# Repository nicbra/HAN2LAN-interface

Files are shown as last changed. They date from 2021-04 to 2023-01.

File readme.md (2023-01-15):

# HAN-to-WLAN interface module
This is a hardware project where the readings of electrical power-meters will be interfaced for logging and display without further interaction with external servers and third-party vendors.

## Hardware
The hardware-module are developed with the Aidon-meters in mind, which is the most used power-meter in eastern Norway.
The hardware-module is a standalone module powered by the HAN-port of the AMS-meter without the neccesity of external power supply. For Aidon, there is a maximum current delivery of 30 mA, which is the highest ammount among the AMS-vendors used in Norway.

## Data parsing
This repository contains only the hardware. You can either write your own firmware for the ESP8266, but I recommend using [AmsToMqttBridge](https://github.com/gskjold/AmsToMqttBridge) from GSkjold.

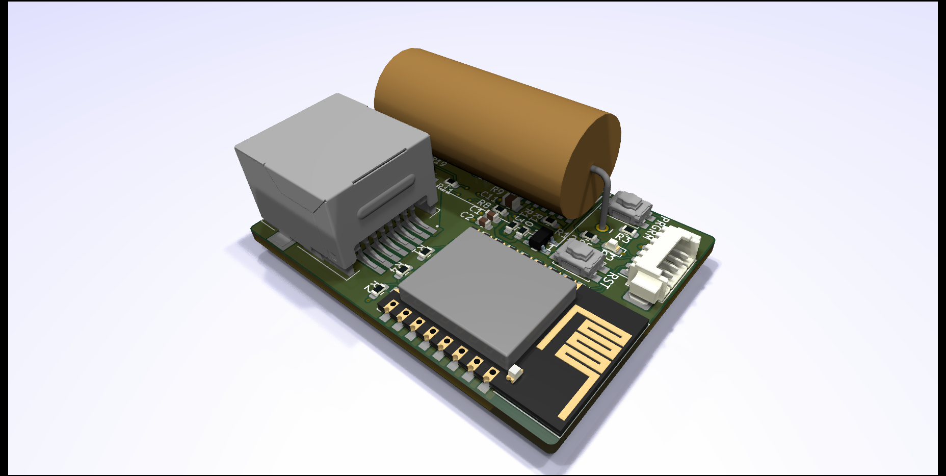
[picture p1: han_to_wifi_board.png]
PCB render


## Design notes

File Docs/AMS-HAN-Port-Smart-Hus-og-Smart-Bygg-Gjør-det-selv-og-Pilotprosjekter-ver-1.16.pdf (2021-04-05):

## Bruk av HAN-port - Gjør-det-selv Smart Hus/Bygg Løsning testet for NURI AMS Måler Bortfall av S0 og bruk av HAN port, versjon 1.15, 2018.06.26

## Bakgrunn

Hele e-verksbransjen og nettselskaper tilknyttet SORIA-alliansen starter nå utskifting av alle våre elektrisitets energimålere til nye AMS målere. Dette gjennomføres i løpet av 2 år framover. Teknologien vi benytter for dagens kWh-måling/fjernavlesning som leverer energipulser (S0) fases ut ved bytte til ny AMS måler.
NEK (https//www.nek.no) har vært sentral mht. standardisering av HAN-porten. Her er det lagt ut informasjon til:
- Utviklere (https://www.nek.no/info-ams-han-utviklere/)
- Brukere (https://www.nek.no/info-ams-han-brukere/)

AMS-måleren som SORIA-alliansen ruller ut vil medføre tilpasning fra nettkunder/leverandører som tidligere har benyttet energipulser (S0) fra dagens målere. Noen av disse kundene bruker denne porten til bl.a. å styre SD anlegg.
De nye AMS målerne for Norge kommer med HAN (Home Area Network) port der måleren kan, om kunden ønsker sende ut data om nåverdier for effektuttaket (kW), energiforbruket (kWh) og strøm- (A) og spenningsforhold (V). Den fysiske pluggen er en RJ45. Det elektriske grensesnittet er basert på MBUS standarden, som leverer nok strøm til at et HAN-adapter kan tilknyttes porten som oversetter meldingene til trådløst format ikke trenger ekstra strømforsyning. Applikasjonsprotokollen er basert på DLMS. Sistnevnte protokoll sender ut meldinger om nevnte strømstørrelser i form av OBIS koder. AMS måler har også en optisk port (IEC 62056-21), men denne er av sikkerhetsmessige grunner stengt fra fabrikken og kan ikke benyttes av kunden.
Flere kraftleverandører har fått Enova-midler til å utvikle en adapter til HAN-porten.
Nettselskapet sin rolle er kun som tilrettelegger for smart hus/smartbygg via den nye standarden for datatilgangen fra den nye AMS måleren.
Oppstilt i OSI-modellen gir dette følgende kommunikasjonsstack:

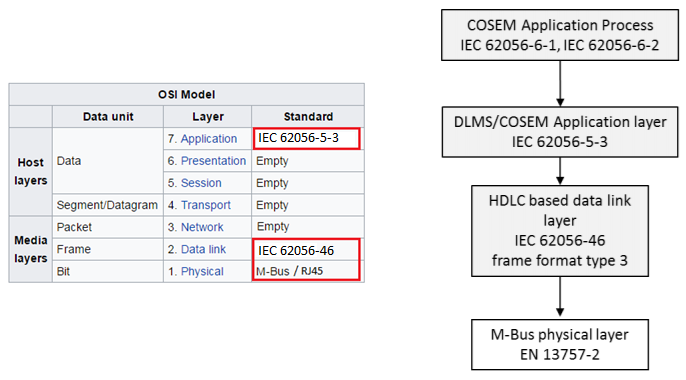
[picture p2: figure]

Fig 1. Protokoller og OSI-modell Fysisk Interface / M-BUS:
- HAN-porten (AMS-måler) er M-Bus Master og kommuniserer BARE med M-Bus SLAVER
- Leverer spenning som er nok til å drive M-Bus SLAVE i andre enden med moderat strømforbruk
- Fysisk Plugg: RJ45
- Baud settings: Hastighet=2400 bit/s, Byte = 8 bit, Parity = Even, Stop bits=1
- Pinner som benyttes: Pin1 og Pin2

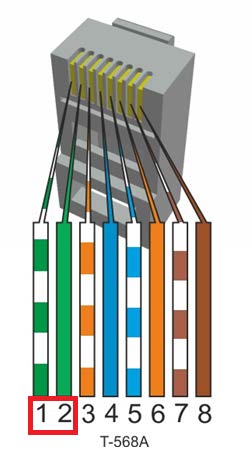
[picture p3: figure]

Fig. RJ45 – Pin1 og Pin2 for MBUS

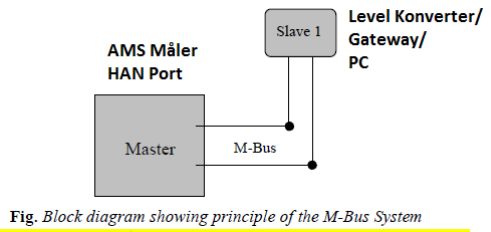
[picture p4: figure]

For HAN-porten er det viktig å merke seg at det BARE skal monteres EN MBUS Slave!
Slaven på HAN-porten skal aldri sende tilbake data til Master (AMS Måler). Om en Slave skulle finne på å sende data til Master vil disse data vil uansett bli ignorert/forkastet av Master.
Overføring av 0/1 bits fra master til slave utføres ved å regulere spenningsnivået. Når det skal sendes ut en logisk
- "1"-er bit benyttes en spenning på +36 V.
- "0"-er bit benyttes en spenning på +24V
Overføring av data fra slave til master skjer ved å endre strømforbruket i slaven:
- En "1"-er bit sendes ved å forbruke opp til 1.5 mA
- En logisk "0"-er bit sendes ved å øke strømforbruket til 11-20 mA

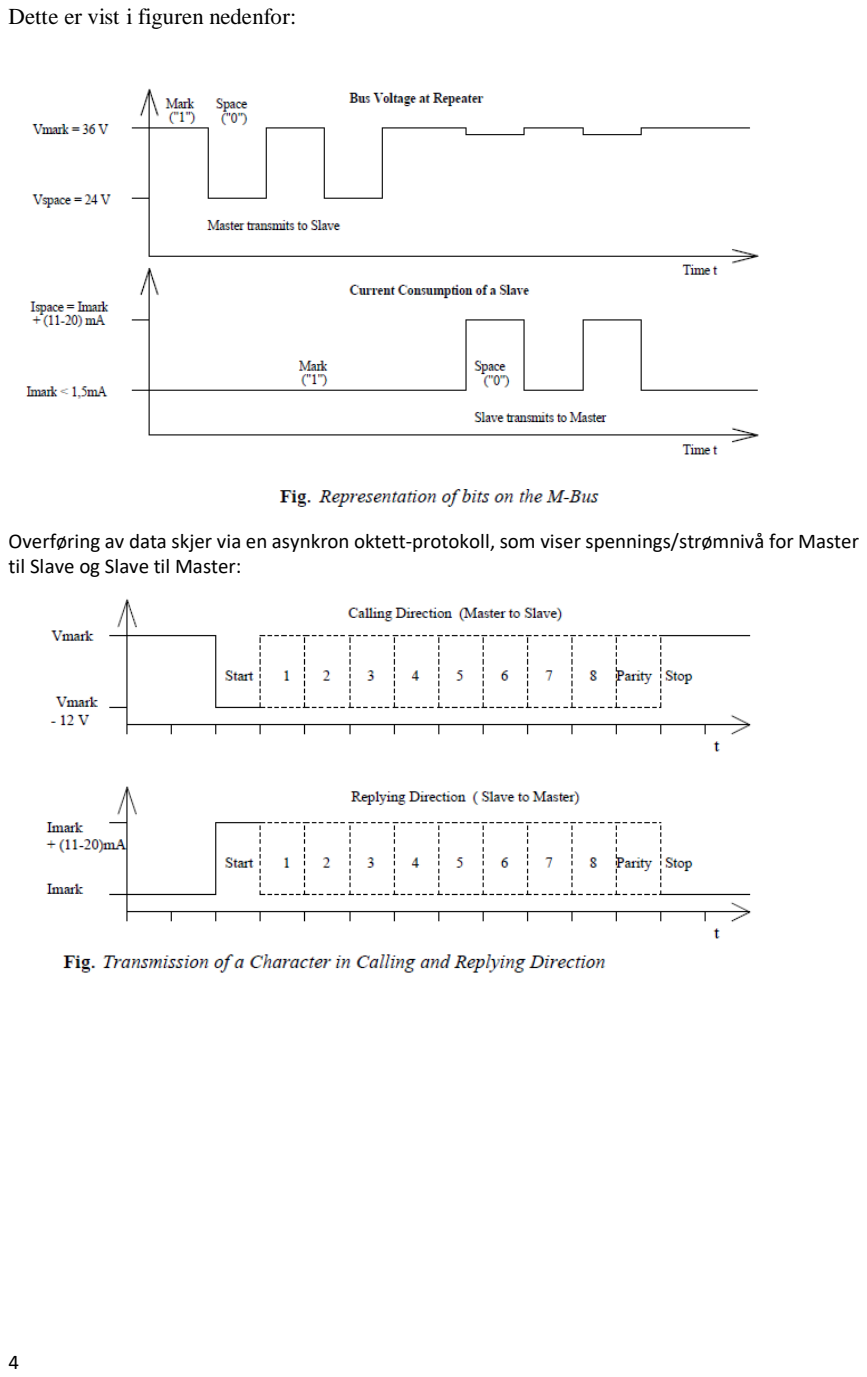
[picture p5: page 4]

Dette er vist i figuren nedenfor:

Overføring av data skjer via en asynkron oktett-protokoll, som viser spennings/strømnivå for Master til Slave og Slave til Master:

Meldingsformatet som kommer ut gir tilgang på følgende verdier:
- Effekt ++ hver 2. sekund
- Effekt ++ og Leveringskvalitet hvert 10. sekund
- Effekt ++, Leveringskvalitet og Energiforbuk (målerstand) hver time

Målerstand i forhold til forrige målerstand vil for en direktekoblet måler tilsvarer det energivolumet som blir oversendt Elhub hver 60 (15) minutt.

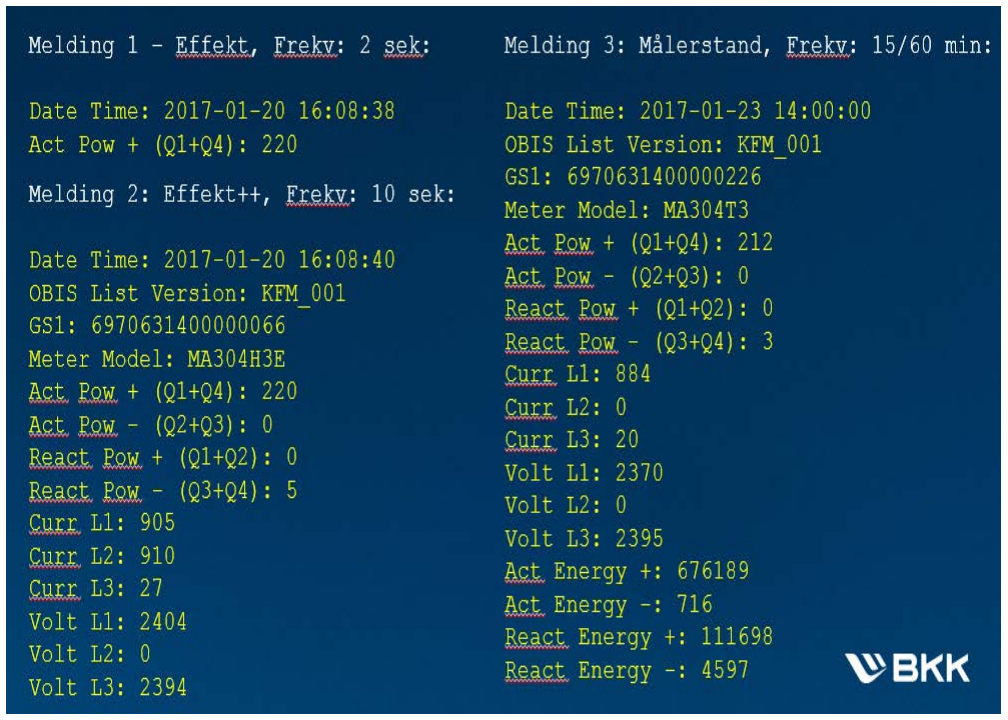
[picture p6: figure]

Fig 2. Eksempel på utskrift av telegrammene

Hvordan bygge en generell Gateway til andre systemer som Z-Wave, KNX etc:

En mulighet er å bruke følgende løsning for en embedded gateway:
- Adapterløsning 1: MBUS til USB med 2 stk. adaptere
- MBUS SLAVE til RS232 (drives av strøm fra HAN-porten)

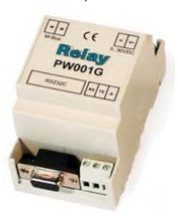
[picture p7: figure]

- USB-til-RS232 kabel (og får strøm fra USB-port) mellom RPi og Relay PW001G
- Søk med «rs232 to usb»

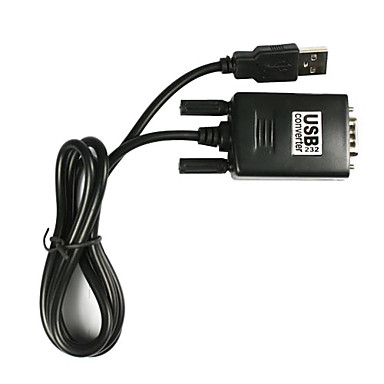
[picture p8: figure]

- Adapterløsning 2 (AliExpress m.fl.): MBUS SLAVE til USB med 1 stk. adapter
- Søk med: «site:aliexpress.com usb to mbus slave»

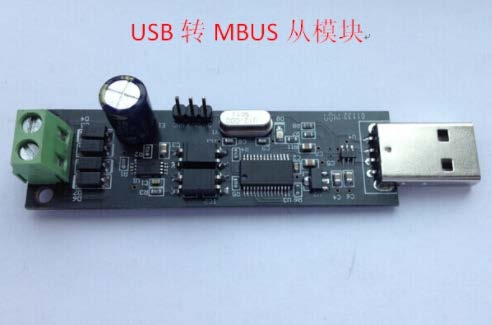
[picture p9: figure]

- Adapterløsning 3: USB-til-M-BUS adapter/kabel (denne har vi bare fått til å virke med Parity = Even som skulle vært None)
- Søk med: «site:aliexpress.com usb to mbus slave»

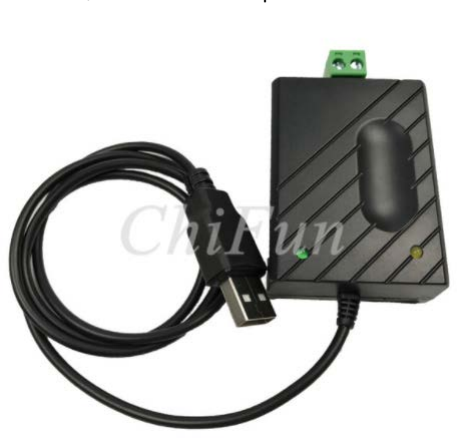
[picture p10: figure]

HAN-Port GW-programvaren kan kjøres på Raspberry Pi (RPi) og derfra interface smartbygg gatewayer fra KNX etc.
Dersom en kjører Raspian (Debian) på RPi dukker serieporten opp som /dev/ttyUSB0 Komponentvalget er her bare en illustrasjon over noe som er å få tak i og som vil virke. MBUS kabel består av et enkelt trådpar.

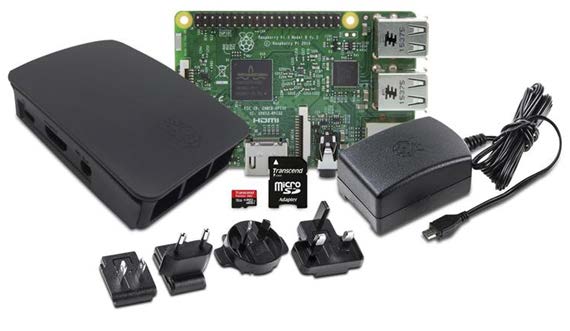
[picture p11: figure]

Fig. Eksempel på RPi kit for å bygge HAN-Gateway
- Søk med «raspberry pi pris»

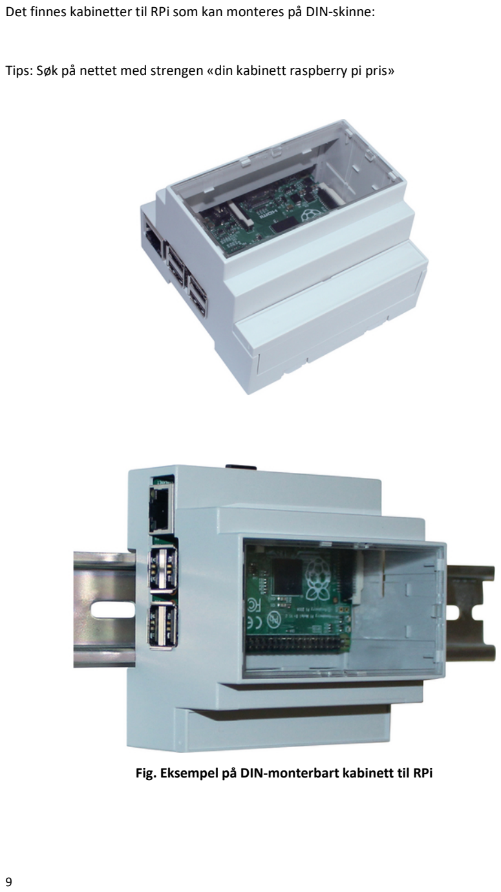
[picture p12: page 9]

Det finnes kabinetter til RPi som kan monteres på DIN-skinne:

Tips: Søk på nettet med strengen «din kabinett raspberry pi pris»

Fig. Eksempel på DIN-monterbart kabinett til RPi

# Figurer - Sammenkobling

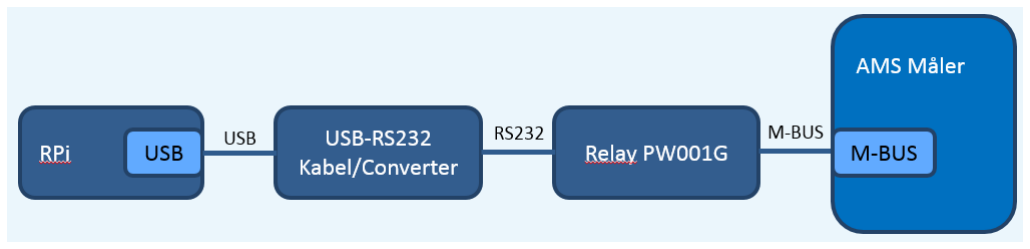
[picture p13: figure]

Fig. Adapterløsning 1 – RS232 til MBUS i egen adapter (Relay PW001G)

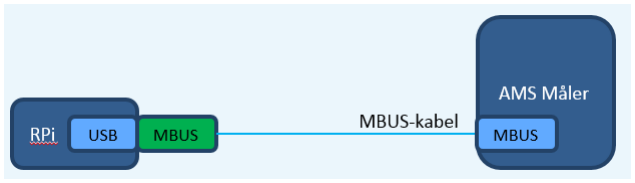
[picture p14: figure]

Fig. Adapterløsning 2 - USB innstikkskort m/ integrert RS232/MBUS konverter

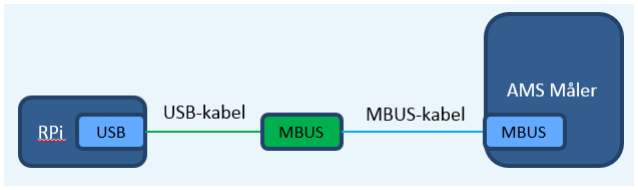
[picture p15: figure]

Fig. Adapterløsning 3 – USB-kabel-til-MBUS-adapter

## Testprogramvare av HAN-port

Programvare for å teste ut eller bruke HAN-porten kan lastes ned fra denne linken: https://drive.google.com/drive/folders/0B3ZvFI0Dg1TDbDBzMU02cnU0Y28?usp=sharing

Programvaren er «as is» og gir ingen rett til reklamasjon eller support fra nettselskapet. Programvaren er bare testet mot Kaifa målere.

## Vedlegg: Kaifa sin implementasjon av NVE / NEK OBIS Spesifikasjon

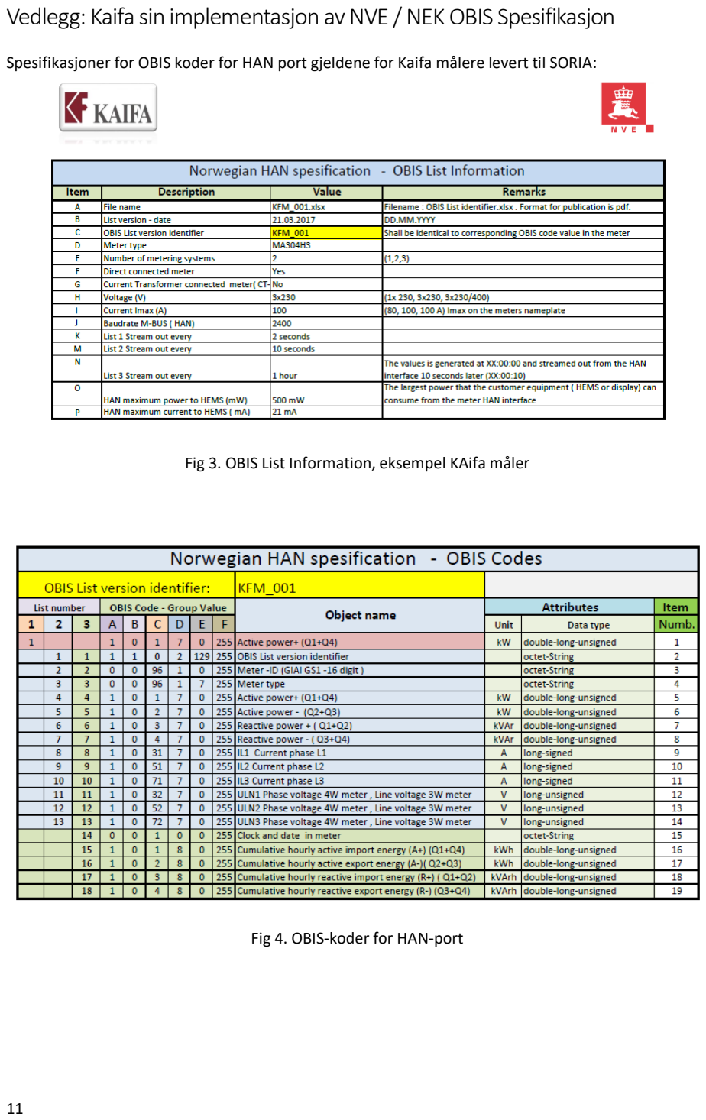
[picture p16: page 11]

Spesifikasjoner for OBIS koder for HAN port gjeldene for Kaifa målere levert til SORIA:

Fig 3. OBIS List Information, eksempel KAifa måler

Fig 4. OBIS-koder for HAN-port

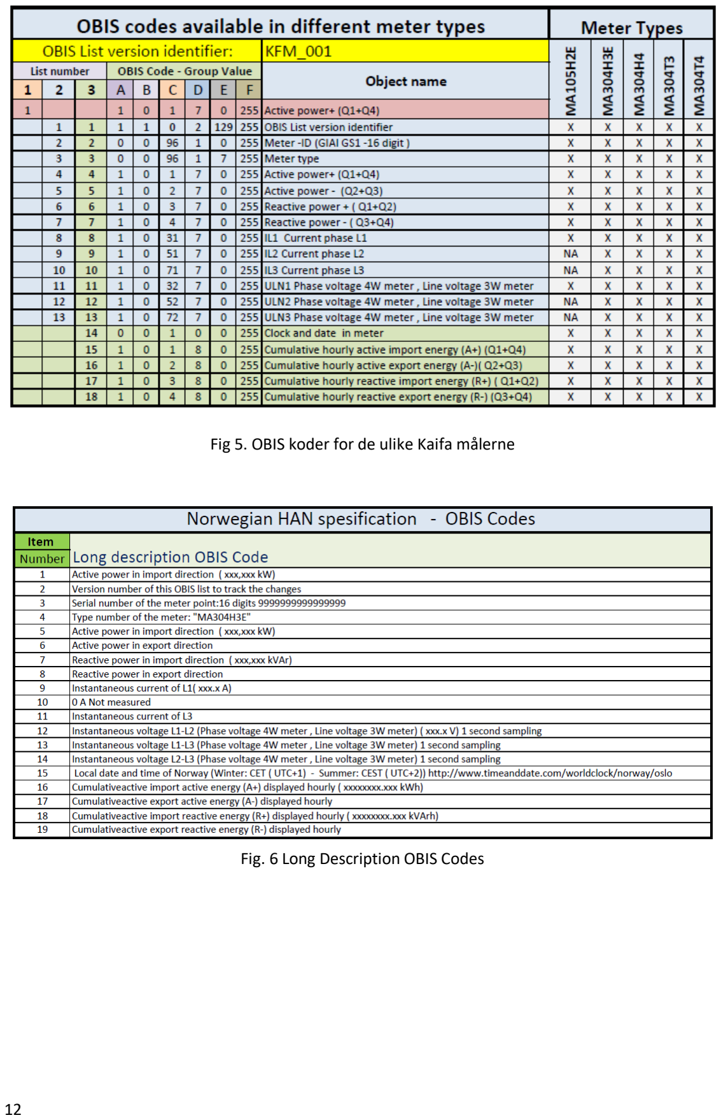
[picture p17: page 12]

Fig 5. OBIS koder for de ulike Kaifa målerne

Fig. 6 Long Description OBIS Codes

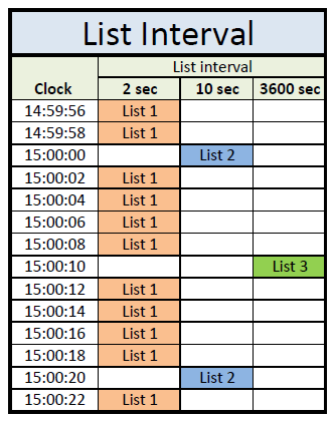
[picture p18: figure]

Fig. 7 Frekvens av telegrammer

# Bruk av HAN-PORT programvare - noen eksempler

## 1. Kildekoden som er på brikken:

### cd ~/src/han-port Oppdaterte tar-filer har katalognavn på formen han-port-<release> Utrulling: cd ~/src <lagre .tar filen her> tar xvf han-port-<release>.tar cd ~/src/han-port-<release>

1.1 Kompiler:

### make clean make

## 2. Hjelp / Hvordan bruke 'test_rx':

### Etter at du har koblet til USB-kabel kommer det dynamisk en ny USB device som typisk heter /dev/ttyUSB0 (hvis dette er den første tty-

USB enheten).

### 2.1 Utfør kommandoen:

### «ls -l /dev/tty* | grep -i usb»

før og etter at du har installert USB donglelen.

### 2.2 Gjør enheten tilgjengelig for vanlige brukere (som root/superbruker):

### sudo su chmod 666 /dev/ttyUSB0 Dette må (pga sikkerheten i Raspbian) gjøres hver gang USB dongelen plugges i! En "quick & dirty" løsning kan være å legge inn 'chmod 666

/dev/ttyUSB0' i en cron jobb som kjøres hvert 5 sekund.

### 2.2 Bruk av test_rx programmet:

### ./test_rx -h

### 2.3 Replay fra fil:

### ./test_rc -f han-data-MA105H2E-2017-01-26_08:00-11:00.dat

### 2.4 Replay fra fil logget fra kryptert HAN-port fil:

### ./test_rx -f han-data-MA105H2E-C00112233445566778899AABBCCDDEEFF-2017-01-25_08:00-12:00.dat -k 00112233445566778899AABBCCDDEEFF

### 2.5 Logging til fil USB/RS232 adapteret mitt som dukker opp som /dev/ttyUSB0 (se hva

som er lagt inn default MACRO i Makefile):

### ./test_rx -d /dev/ttyUSB0

### 2.6 Bare logging til skjerm:

### ./test_rx -n -d /dev/ttyUSB0

### 2.7 Multicast meldingene videre på LAN-et:

### ./test_rx -m -n -d /dev/ttyUSB0

### 2.8 Multicast meldingene som leses fra fil, lager 1s pause etter hver multicast sending

### ./test_rx -M -f han-data-MA304T3-2017-01-23_13:03-15:57.dat

### 2.9 Mottak av multicast fra en annen pi/pc/whatever

### ./test_rx -l

### 2.10 Setting av paritet

Vi har testet en MBUS «dongle» som har tolker paritet feil. Paritet skal være N(one), men den må i visse tilfeller settes til E(ven) eller O(dd). Hvis det ikke virker, prøv alternativ paritet med:

### ./test_rx -n -P E eller ./test_rc -n P O

# Markedsaktører

## Smart Hus / Smart Bygg

Utviklere av HAN-adapter og SW løsninger:

- EM Systemer (Smart Bygg?)
- http://www.emsystemer.no/
- Hark Technology (Smart Hus?)
- http://www.harktech.no/
- Red Bridge (Smart Hus?)
- http://redbridge.no
- Sikom Living (Smart Hus?)
- http://www.sikom.no/nb
- Vord (Smart Hus?)
- https://vord.no/

## Do-It-Yourself (DIY) prosjekter

Det finnes også entusiaster som har laget HW/SW-løsninger til HAN-porten. På Github ligger det beskrivelse av hvordan kyndige kan bygge sin egen adapter for WiFi og som får energiforsyning fra HAN-porten. Her ligger det også programvare for bruk av adapteren.

https://github.com/roarfred

Det er uklart om noen vil overta vedlikeholdet eller videreutvikling av denne programvaren.

## Enova støttede AMS-prosjekter

Enova sin link til prosjekjene:

- https://www.enova.no/privat/smarte-strommalere-ams/enova-og-ams/
Formål:

Prosjektet skal avdekke hvilke typer løsninger som er best egnet til å motivere til å spare
strøm. Dette blir et nyttig prosjekt for bransjen som helhet. Nå vil man ikke lenger trenge å spekulere på hva som vil fungere, nå finner vi det ut. 25 000 strømabonnenter er et stort utvalg som vil gi pålitelige svar om hva slags type løsninger som virker og ikke virker.

Her vil det komme tekniske løsninger for sanntidskommunikasjon fra HAN-porten, de første vil forventes å komme mot slutten av Q4 2017.
Eksempel på løsning fra Fjordkraft:

Pilotkunden får to «dongler» som er fabrikkparet slik at det bare skal monteres, ingen konfigurasjon er aktivering er nødvendig. Data sendes kryptert hvert 2. sekund til en tjeneste i «skyen».

Dongle 1:

Kobles til HAN-port på måler og trekker strøm fra HAN-porten. Den sender data kryptert på radio i 868 MHz fribruksområdet til Dongle 2 som vist i bildet under:

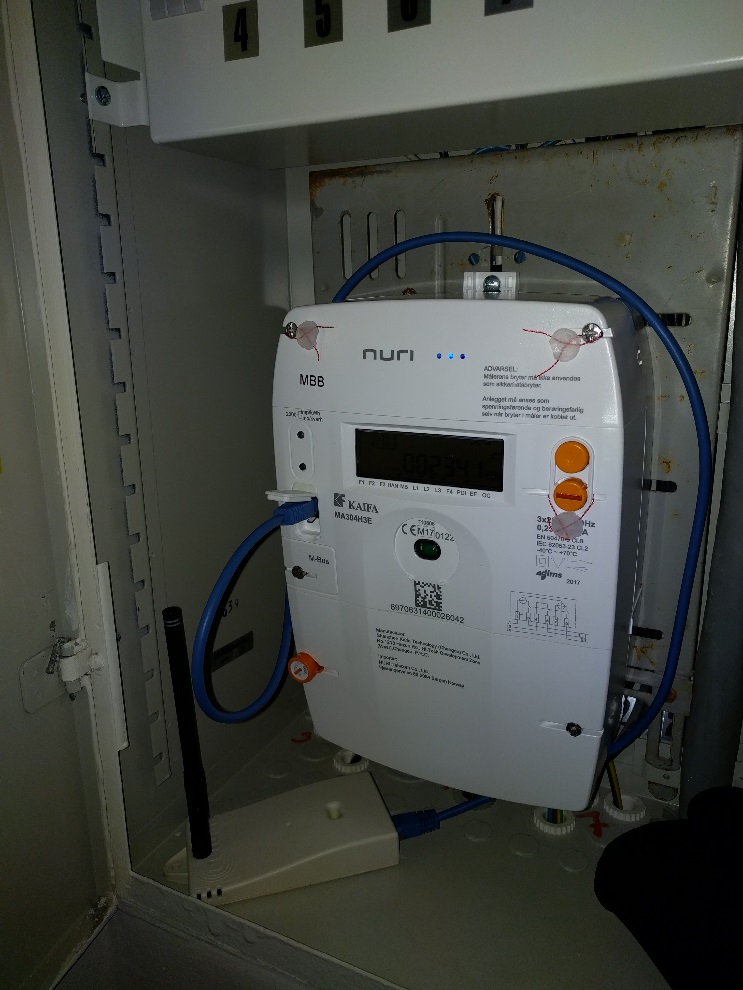
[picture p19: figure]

Fig. HAN dongle koblet til HAN-port

Dongle 2:

Denne kobles til en ethernett port på en hjemmeruter (typisk en WiFi ruter) og mottar data fra Dongle 1. Dongle 2 sender data videre kryptert via Internettlinjen til en skytjeneste.

Dongle 2 må forsynes med strøm via en Mikro-USB kabel som vist i bildet under:

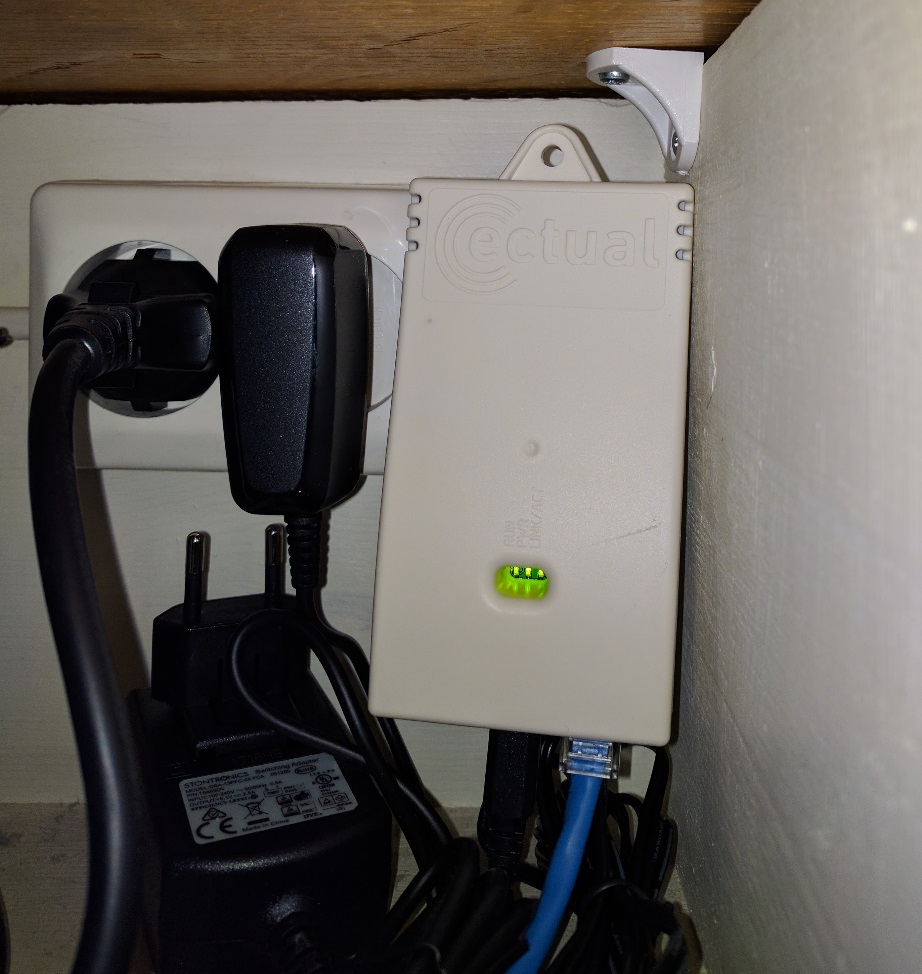
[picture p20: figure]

Fig. Tilknytning av Hjemmeruter-dongle

Skytjeneste og bruk av app:

Kunden får tilgang til data og forbruk via egen app tilpasset smarte mobiler. Forventes lansert i løpet av Q1 2018.

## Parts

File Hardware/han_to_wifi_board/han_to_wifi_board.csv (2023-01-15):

Source: | /home/nicholas/Documents/Prosjekter/HAN2WLAN-interface/Hardware/han_to_wifi_board/han_to_wifi_board.kicad_sch
Date: | lø. 14. mai 2022 kl. 12.52 +0200
Tool: | Eeschema 6.0.5-a6ca702e91~116~ubuntu20.04.1
Generator: | /usr/share/kicad/plugins/bom_csv_grouped_by_value.py
Component Count: | 35
Individual Components:
Item | Qty | Reference(s) | Value | LibPart | Footprint | Datasheet | Arrow Part Number | Arrow Price/Stock | Description | Height | Manufacturer_Name | Manufacturer_Part_Number | Mouser Part Number | Mouser Price/Stock | Spice_Netlist_Enabled | Spice_Primitive
 |  | C1 | 100n | Device:C_Small | Capacitor_SMD:C_0603_1608Metric | ~
 |  | C2 | 10µ | Device:C_Small | Capacitor_SMD:C_0603_1608Metric | ~
 |  | C3 | 1F | Device:C_Polarized_Small | MAL202117102E3:MAL202117102E3 | ~
 |  | C6 | 10µ | Device:C_Polarized_Small | Capacitor_SMD:C_0603_1608Metric | ~
 |  | C7 | 220n | Device:C_Small | Capacitor_SMD:C_0603_1608Metric | ~
 |  | C11 | 1µ | Device:C_Small | Capacitor_SMD:C_0805_2012Metric | ~
 |  | C12 | 4.7µF | Device:C_Small | Capacitor_SMD:C_0805_2012Metric | ~
 |  | C18 | 2.2µF | Device:C_Small | Capacitor_SMD:C_0603_1608Metric | ~
 |  | C19 | 5600pF | Device:C_Small | Capacitor_SMD:C_0603_1608Metric | ~
 |  | C20 | 0.1µF | Device:C_Small | Capacitor_SMD:C_0603_1608Metric | ~
 |  | C21 | 47µF | Device:C_Small | Capacitor_SMD:C_0805_2012Metric | ~
 |  | D2 | 700mV, 2A | Device:D_Schottky | Diode_SMD:D_SMA | ~
 |  | D3 | LED | Device:LED | LED_SMD:LED_0603_1608Metric | ~
 |  | D4 | NSI45025AT1G | NSI45025AT1G:NSI45025AT1G | NSI45025AT1G:NSI45025AT1G | http://www.onsemi.com/pub/Collateral/NSI45025A-D.PDF | NSI45025AT1G | https://www.arrow.com/en/products/nsi45025at1g/on-semiconductor | Constant Current Regulator | 1.35 | ON Semiconductor | NSI45025AT1G | 863-NSI45025AT1G | https://www.mouser.co.uk/ProductDetail/ON-Semiconductor/NSI45025AT1G/?qs=lYuAOLy5nvbSAhXoRwekbg%3D%3D | Y | I
 |  | IC1 | MIC2779L-2YM5_TR | MIC2779L-1YM5_TR:MIC2779L-2YM5_TR | MIC2779L:SOT95P280X145-5N | https://ww1.microchip.com/downloads/en/DeviceDoc/MIC2779-Voltage-Monitor-with-Adjustable-Hysteresis-DS20006116A.pdf | MIC2779L-2YM5 TR | https://www.arrow.com/en/products/mic2779l-1ym5-tr/microchip-technology | Voltage Monitor 5-Pin SOT-23 T/R | 1.45 | Microchip | MIC2779L-2YM5 TR
 |  | IC3 | MAX17644AATE+ | MAX17644AATE+:MAX17644AATE+ | QFN50P300X300X80-17N | https://datasheets.maximintegrated.com/en/ds/MAX17644.pdf |  |  | Switching Voltage Regulators 4.5V to 36V, 2.7A, H igh-Efficiency, Syn | 0.8 | Maxim Integrated | MAX17644AATE+ | 700-MAX17644AATE+ | https://www.mouser.co.uk/ProductDetail/Maxim-Integrated/MAX17644AATE%2b?qs=TuK3vfAjtkWmvUqRGOIJnQ%3D%3D
 |  | J1 | RJLSE4118101 | RJLSE4118101:RJLSE4118101 | RJLSE4118101:RJLSE4118101 | http://www.amphenol-icc.com/media/wysiwyg/files/drawing/rjlse4x1xx01.pdf |  |  | Modular Connectors / Ethernet Connectors 8P8C SMT Shielded 1 Port | 12.32 | Amphenol | RJLSE4118101 | 523-RJLSE4118101 | https://www.mouser.co.uk/ProductDetail/Amphenol-Commercial-Products/RJLSE4118101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
 |  | J3 | Conn_01x05_Male | Connector:Conn_01x05_Male | Connector_Molex:Molex_PicoBlade_53261-0571_1x05-1MP_P1.25mm_Horizontal | ~
 |  | L3 | 5.6µH | Device:L_Small | Inductor_SMD:L_Vishay_IHLP-2020 | ~
 |  | R1 | 10k | Device:R_Small | Resistor_SMD:R_0402_1005Metric | ~
 |  | R2 | 10k | Device:R_Small | Resistor_SMD:R_0402_1005Metric | ~
 |  | R3 | 10k | Device:R_Small | Resistor_SMD:R_0402_1005Metric | ~
 |  | R4 | 10k | Device:R_Small | Resistor_SMD:R_0402_1005Metric | ~
 |  | R5 | 750R | Device:R_Small | Resistor_SMD:R_0603_1608Metric | ~
 |  | R7 | 30k | Device:R_Small | Resistor_SMD:R_0402_1005Metric | ~
 |  | R8 | 825k | Device:R | Resistor_SMD:R_0402_1005Metric | ~
 |  | R9 | 220R | Device:R_Small | Resistor_SMD:R_0603_1608Metric | ~
 |  | R10 | 121k | Device:R | Resistor_SMD:R_0402_1005Metric | ~
 |  | R11 | 220R | Device:R_Small | Resistor_SMD:R_0603_1608Metric | ~
 |  | R12 | 100R | Device:R_Small | Resistor_SMD:R_0603_1608Metric | ~
 |  | R13 | 56k2 | Device:R | Resistor_SMD:R_0402_1005Metric | ~
 |  | R19 | 40k2 | Device:R_Small | Resistor_SMD:R_0603_1608Metric | ~
 |  | SW1 | RESET | Switch:SW_Push_Dual | Button_Switch_SMD:SW_SPST_EVQP2 | ~
 |  | U1 | ESP-12F | RF_Module:ESP-12F | RF_Module:ESP-12E | http://wiki.ai-thinker.com/_media/esp8266/esp8266_series_modules_user_manual_v1.1.pdf
 |  | U3 | NCN5150 | NCN5150:NCN5150 | NCN5150DR2G:SOIC127P600X175-16N
Collated Components:
Item | Qty | Reference(s) | Value | LibPart | Footprint | Datasheet | Arrow Part Number | Arrow Price/Stock | Description | Height | Manufacturer_Name | Manufacturer_Part_Number | Mouser Part Number | Mouser Price/Stock | Spice_Netlist_Enabled | Spice_Primitive
1 | 1 | C1 | 100n | Device:C_Small | Capacitor_SMD:C_0603_1608Metric | ~
2 | 1 | C2 | 10µ | Device:C_Small | Capacitor_SMD:C_0603_1608Metric | ~
3 | 1 | C3 | 1F | Device:C_Polarized_Small | MAL202117102E3:MAL202117102E3 | ~
4 | 1 | C6 | 10µ | Device:C_Polarized_Small | Capacitor_SMD:C_0603_1608Metric | ~
5 | 1 | C7 | 220n | Device:C_Small | Capacitor_SMD:C_0603_1608Metric | ~
6 | 1 | C11 | 1µ | Device:C_Small | Capacitor_SMD:C_0805_2012Metric | ~
7 | 1 | C12 | 4.7µF | Device:C_Small | Capacitor_SMD:C_0805_2012Metric | ~
8 | 1 | C18 | 2.2µF | Device:C_Small | Capacitor_SMD:C_0603_1608Metric | ~
9 | 1 | C19 | 5600pF | Device:C_Small | Capacitor_SMD:C_0603_1608Metric | ~
10 | 1 | C20 | 0.1µF | Device:C_Small | Capacitor_SMD:C_0603_1608Metric | ~
11 | 1 | C21 | 47µF | Device:C_Small | Capacitor_SMD:C_0805_2012Metric | ~
12 | 1 | D2 | 700mV, 2A | Device:D_Schottky | Diode_SMD:D_SMA | ~
13 | 1 | D3 | LED | Device:LED | LED_SMD:LED_0603_1608Metric | ~
14 | 1 | D4 | NSI45025AT1G | NSI45025AT1G:NSI45025AT1G | NSI45025AT1G:NSI45025AT1G | http://www.onsemi.com/pub/Collateral/NSI45025A-D.PDF | NSI45025AT1G | https://www.arrow.com/en/products/nsi45025at1g/on-semiconductor | Constant Current Regulator | 1.35 | ON Semiconductor | NSI45025AT1G | 863-NSI45025AT1G | https://www.mouser.co.uk/ProductDetail/ON-Semiconductor/NSI45025AT1G/?qs=lYuAOLy5nvbSAhXoRwekbg%3D%3D | Y | I
15 | 1 | IC1 | MIC2779L-2YM5_TR | MIC2779L-1YM5_TR:MIC2779L-2YM5_TR | MIC2779L:SOT95P280X145-5N | https://ww1.microchip.com/downloads/en/DeviceDoc/MIC2779-Voltage-Monitor-with-Adjustable-Hysteresis-DS20006116A.pdf | MIC2779L-2YM5 TR | https://www.arrow.com/en/products/mic2779l-1ym5-tr/microchip-technology | Voltage Monitor 5-Pin SOT-23 T/R | 1.45 | Microchip | MIC2779L-2YM5 TR
16 | 1 | IC3 | MAX17644AATE+ | MAX17644AATE+:MAX17644AATE+ | QFN50P300X300X80-17N | https://datasheets.maximintegrated.com/en/ds/MAX17644.pdf |  |  | Switching Voltage Regulators 4.5V to 36V, 2.7A, H igh-Efficiency, Syn | 0.8 | Maxim Integrated | MAX17644AATE+ | 700-MAX17644AATE+ | https://www.mouser.co.uk/ProductDetail/Maxim-Integrated/MAX17644AATE%2b?qs=TuK3vfAjtkWmvUqRGOIJnQ%3D%3D
17 | 1 | J1 | RJLSE4118101 | RJLSE4118101:RJLSE4118101 | RJLSE4118101:RJLSE4118101 | http://www.amphenol-icc.com/media/wysiwyg/files/drawing/rjlse4x1xx01.pdf |  |  | Modular Connectors / Ethernet Connectors 8P8C SMT Shielded 1 Port | 12.32 | Amphenol | RJLSE4118101 | 523-RJLSE4118101 | https://www.mouser.co.uk/ProductDetail/Amphenol-Commercial-Products/RJLSE4118101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
18 | 1 | J3 | Conn_01x05_Male | Connector:Conn_01x05_Male | Connector_Molex:Molex_PicoBlade_53261-0571_1x05-1MP_P1.25mm_Horizontal | ~
19 | 1 | L3 | 5.6µH | Device:L_Small | Inductor_SMD:L_Vishay_IHLP-2020 | ~
20 | 4 | R1, R2, R3, R4 | 10k | Device:R_Small | Resistor_SMD:R_0402_1005Metric | ~
21 | 1 | R5 | 750R | Device:R_Small | Resistor_SMD:R_0603_1608Metric | ~
22 | 1 | R7 | 30k | Device:R_Small | Resistor_SMD:R_0402_1005Metric | ~
23 | 1 | R8 | 825k | Device:R | Resistor_SMD:R_0402_1005Metric | ~
24 | 2 | R9, R11 | 220R | Device:R_Small | Resistor_SMD:R_0603_1608Metric | ~
25 | 1 | R10 | 121k | Device:R | Resistor_SMD:R_0402_1005Metric | ~
26 | 1 | R12 | 100R | Device:R_Small | Resistor_SMD:R_0603_1608Metric | ~
27 | 1 | R13 | 56k2 | Device:R | Resistor_SMD:R_0402_1005Metric | ~
28 | 1 | R19 | 40k2 | Device:R_Small | Resistor_SMD:R_0603_1608Metric | ~
29 | 1 | SW1 | RESET | Switch:SW_Push_Dual | Button_Switch_SMD:SW_SPST_EVQP2 | ~
30 | 1 | U1 | ESP-12F | RF_Module:ESP-12F | RF_Module:ESP-12E | http://wiki.ai-thinker.com/_media/esp8266/esp8266_series_modules_user_manual_v1.1.pdf
31 | 1 | U3 | NCN5150 | NCN5150:NCN5150 | NCN5150DR2G:SOIC127P600X175-16N

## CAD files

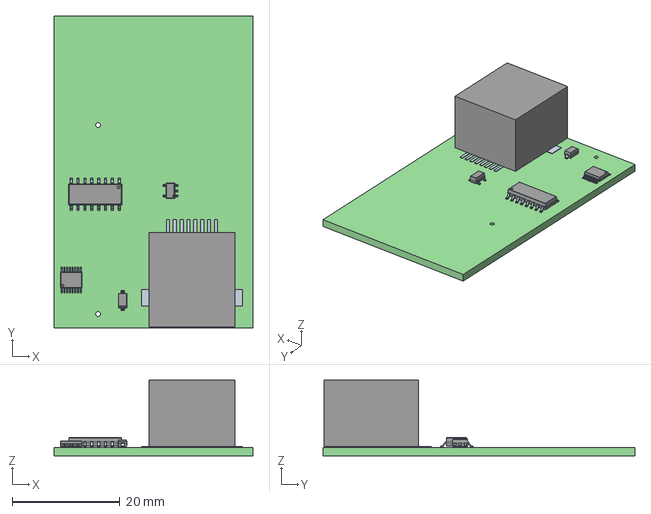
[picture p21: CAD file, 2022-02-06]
Hardware/han_to_wifi_board/han_to_wifi_board.step
36.8 x 57.8 x 14.1 mm
han_to_wifi_board PCB

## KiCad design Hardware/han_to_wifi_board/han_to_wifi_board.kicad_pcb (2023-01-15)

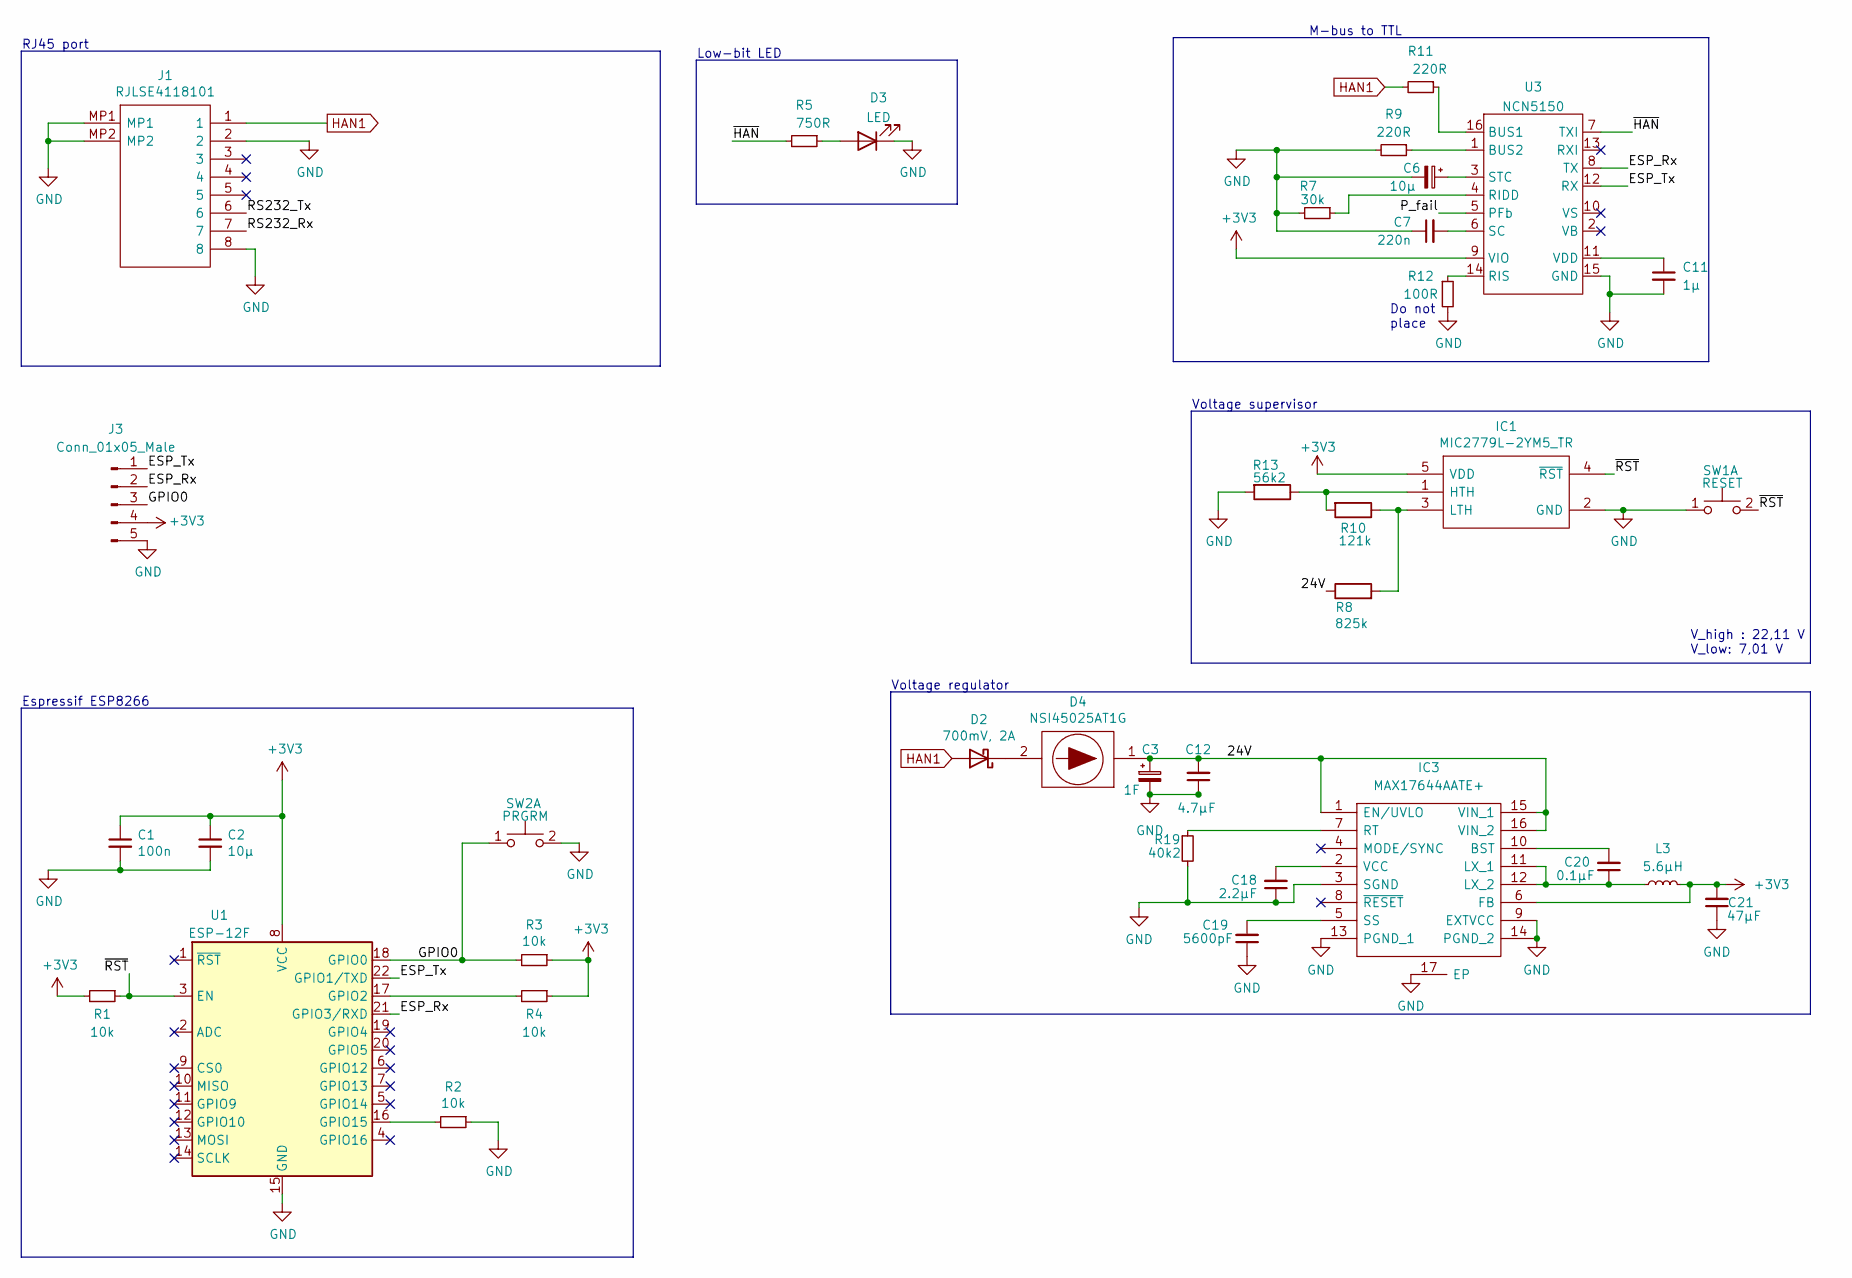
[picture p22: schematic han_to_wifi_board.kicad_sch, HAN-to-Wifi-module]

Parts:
C1: 100n; C_0603_1608Metric
C2, C6: 10µ; C_0603_1608Metric
C3: 1F; MAL202117102E3
C7: 220n; C_0603_1608Metric
C11: 1µ; C_0805_2012Metric
C12: 4.7µF; C_0805_2012Metric
C18: 2.2µF; C_0603_1608Metric
C19: 5600pF; C_0603_1608Metric
C20: 0.1µF; C_0603_1608Metric
C21: 47µF; C_0805_2012Metric
D2: 700mV, 2A; D_SMA
D3: LED; LED_0603_1608Metric
D4: NSI45025AT1G; Manufacturer_Part_Number NSI45025AT1G; Mouser Part Number 863-NSI45025AT1G
IC1: MIC2779L-2YM5_TR; SOT95P280X145-5N; Manufacturer_Part_Number MIC2779L-2YM5 TR
IC3: MAX17644AATE+; QFN50P300X300X80-17N; Manufacturer_Part_Number MAX17644AATE+; Mouser Part Number 700-MAX17644AATE+
J1: RJLSE4118101; Manufacturer_Part_Number RJLSE4118101; Mouser Part Number 523-RJLSE4118101
J3: Conn_01x05_Male; Molex_PicoBlade_53261-0571_1x05-1MP_P1.25mm_Horizontal
L3: 5.6µH; L_Vishay_IHLP-2020
R1, R2, R3, R4: 10k; R_0603_1608Metric
R5: 750R; R_0603_1608Metric
R7: 30k; R_0603_1608Metric
R8: 825k; R_0603_1608Metric
R9, R11: 220R; R_0603_1608Metric
R10: 121k; R_0603_1608Metric
R12: 100R; R_0603_1608Metric
R13: 56k2; R_0603_1608Metric
R19: 40k2; R_0603_1608Metric
SW1: RESET; EVQP2
SW2: PRGRM; EVQP2
U1: ESP-12F; ESP-12E
U3: NCN5150; SOIC127P600X175-16N

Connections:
+3V3: C1.1, C2.1, C21.2, IC1.5 (VDD), IC3.6 (FB), J3.4, L3.2, R1.2, R3.1, R4.1, U1.8 (VCC), U3.9 (VIO)
/24V: C3.1, C12.2, D4.1, IC3.1 (EN/UVLO), IC3.15 (VIN_1), IC3.16 (VIN_2), R8.1
/ESP_Rx: J3.2, U1.21 (GPIO3/RXD), U3.8 (TX)
/ESP_Tx: J3.1, U1.22 (GPIO1/TXD), U3.12 (RX)
/GPIO0: J3.3, R3.2, SW2.1 (C), U1.18 (GPIO0)
/P_fail: U3.5 (PFb)
/RS232_Rx: J1.7
/RS232_Tx: J1.6
/~HAN: R5.2, U3.7 (TXI)
/~RST: IC1.4 (~RST), R1.1, SW1.2 (D), U1.3 (EN)
GND: C1.2, C2.2, C3.2, C6.2, C7.1, C11.2, C12.1, C18.1, C19.1, C21.1, D3.1 (K), IC1.2 (GND), IC3.3 (SGND), IC3.9 (EXTVCC), IC3.13 (PGND_1), IC3.14 (PGND_2), IC3.17 (EP), J1.2, J1.8, J1.MP1, J1.MP2, J3.5, R2.1, R7.2, R9.2, R12.2, R13.2, R19.2, SW1.1 (C), SW2.2 (D), U1.15 (GND), U3.15 (GND)
HAN1: D2.2 (A), J1.1, R11.2
unnamed: C6.1, U3.3 (STC)
unnamed: C7.2, U3.6 (SC)
unnamed: C11.1, U3.11 (VDD)
unnamed: C18.2, IC3.2 (VCC)
unnamed: C19.2, IC3.5 (SS)
unnamed: C20.1, IC3.11 (LX_1), IC3.12 (LX_2), L3.1
unnamed: C20.2, IC3.10 (BST)
unnamed: D2.1 (K), D4.2
unnamed: D3.2 (A), R5.1
unnamed: IC1.1 (HTH), R10.2, R13.1
unnamed: IC1.3 (LTH), R8.2, R10.1
unnamed: IC3.7 (RT), R19.1
unnamed: R2.2, U1.16 (GPIO15)
unnamed: R4.2, U1.17 (GPIO2)
unnamed: R7.1, U3.4 (RIDD)
unnamed: R9.1, U3.1 (BUS2)
unnamed: R11.1, U3.16 (BUS1)
unnamed: R12.1, U3.14 (RIS)

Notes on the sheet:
Espressif ESP8266
M-bus to TTL
Voltage regulator
Do not place
Voltage supervisor
RJ45 port
Low-bit LED
V_high : 22,11 V V_low: 7,01 V

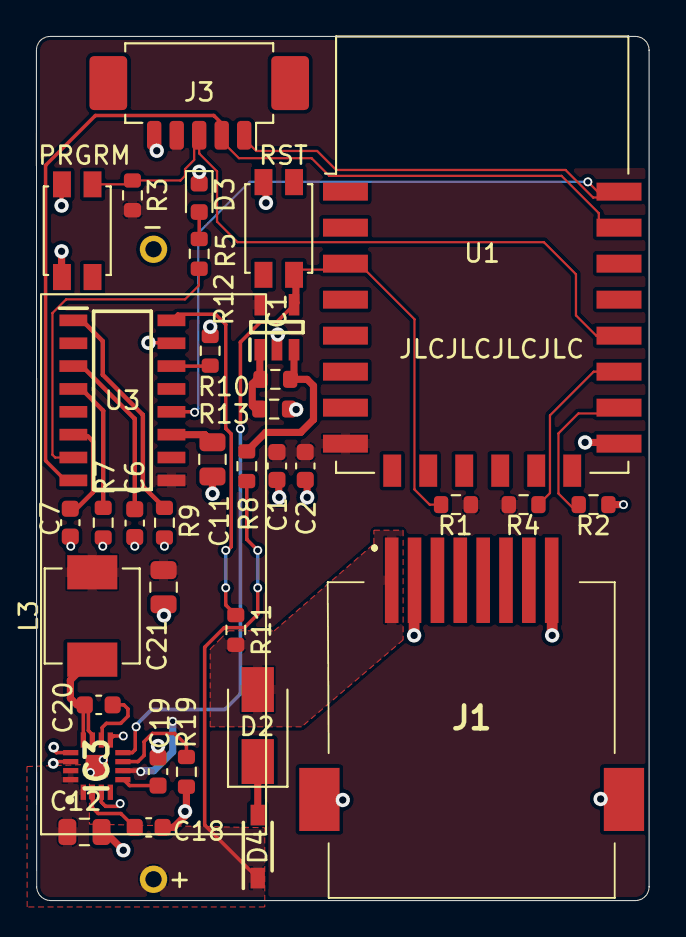
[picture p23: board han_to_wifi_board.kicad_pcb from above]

Board: 2 copper layers, 34.0 x 48.0 mm, 36 parts (0 on the bottom side), 27 nets.

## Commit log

2022-02-06 Moved to kicad6 and finished board
    [han_to_wifi_board-B_Cu.gbl, han_to_wifi_board-B_Cu.gbr, han_to_wifi_board-B_Mask.gbr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]
2022-05-04 New buck converter
    [han_to_wifi_board-B_Cu.gbl, han_to_wifi_board-B_Cu.gbr, han_to_wifi_board-B_Mask.gbr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]
2022-05-14 Added BOM
    [han_to_wifi_board.csv]
2022-05-18 Connected SGND on buck to GND
    [han_to_wifi_board.kicad_pcb, han_to_wifi_board.kicad_sch]
2022-08-10 Reset pin on buck
    [han_to_wifi_board.kicad_sch]
2022-09-13 September hw changes
    [han_to_wifi_board-B_Cu.gbl, han_to_wifi_board-B_Mask.gbs, han_to_wifi_board-B_Paste.gbp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]
2023-01-15 Changes after first bringup
    [han_to_wifi_board.kicad_pcb, han_to_wifi_board.kicad_sch]
